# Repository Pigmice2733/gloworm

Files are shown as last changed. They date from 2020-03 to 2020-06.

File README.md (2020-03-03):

# Gloworm

A Raspberry Pi vision tracking module for FRC.

* Powered directly off the PDP (built-in Raspberry Pi PSU)
* Cheap, utilizing off the shelf parts and a 3D printed case (~$120 including RPi 4, camera, PCB, fasteners)
* Fully dimmable ~500 lumen output (6x Cree XP-E2 Green LEDs)
* Compact design (100mm x 74mm x 25mm)

<br />This work is licensed under a <a rel="license" href="http://creativecommons.org/licenses/by-nc-sa/4.0/">Creative Commons Attribution-NonCommercial-ShareAlike 4.0 International License</a>.

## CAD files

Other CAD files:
case/Assembled Gloworm.SLDASM
case/Raspberry Pi 4.SLDPRT
case/M2.5 11mm Spacer.SLDPRT
case/Gloworm PCB.SLDPRT
case/Bottom Case.SLDPRT
case/Top Case.SLDPRT
case/Camera Module.SLDPRT

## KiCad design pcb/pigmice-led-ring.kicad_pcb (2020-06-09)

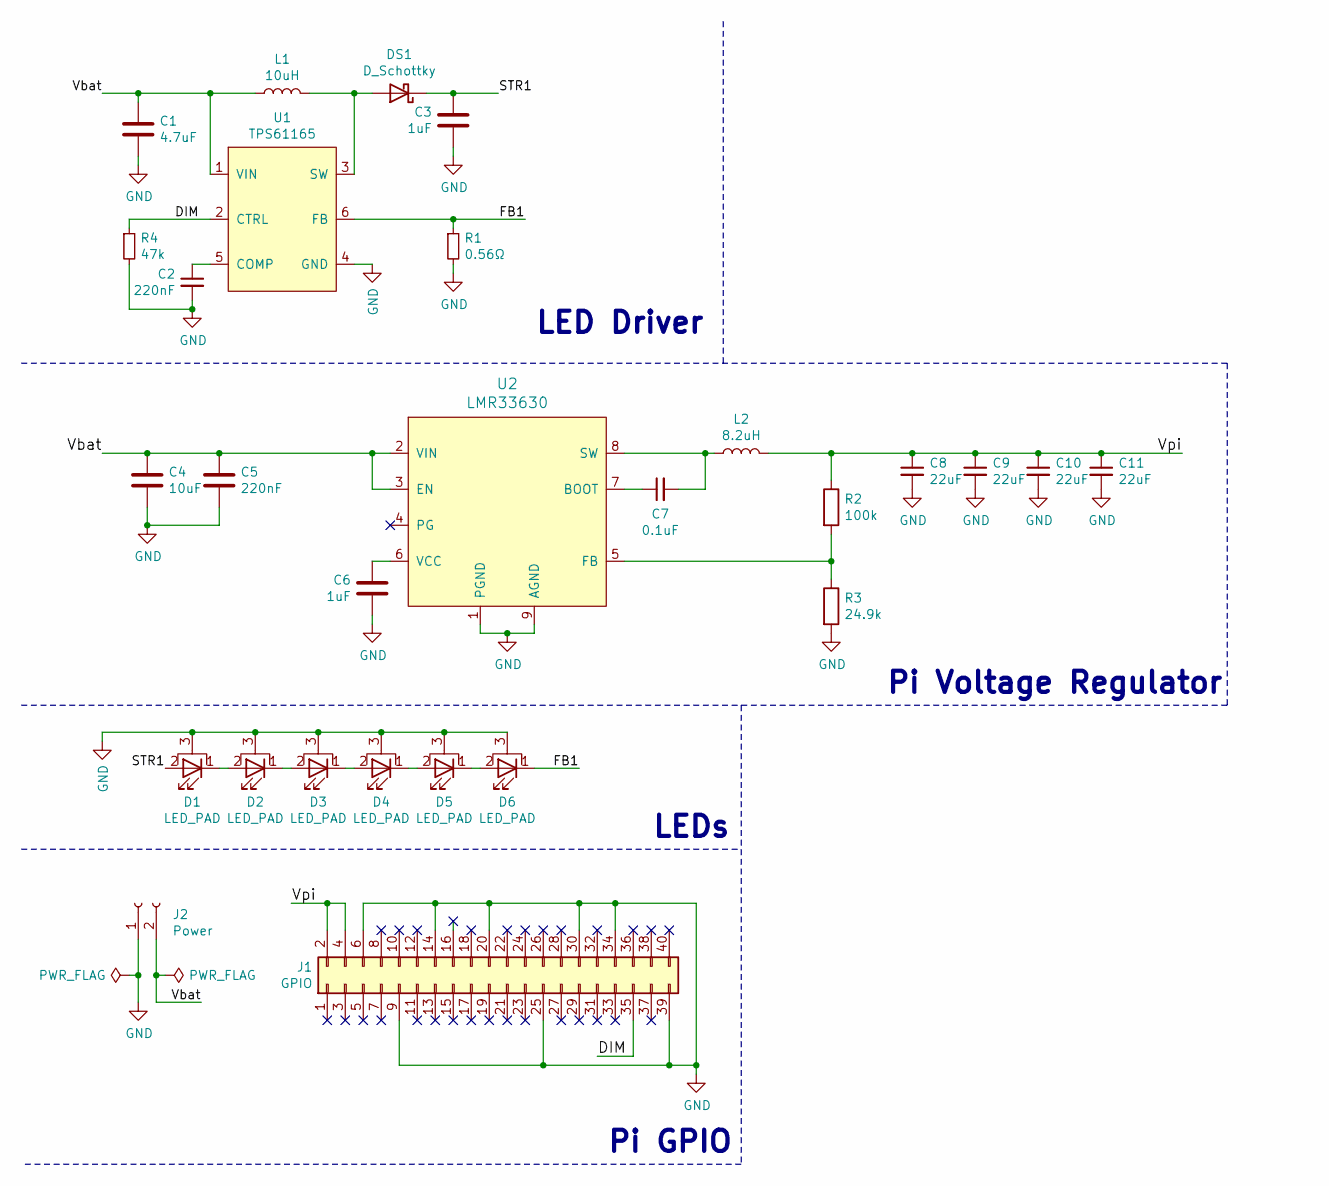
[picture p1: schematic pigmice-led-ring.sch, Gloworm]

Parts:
C1: 4.7uF; C_0805_2012Metric; Digikey 445-172480-1-ND
C2: 220nF; C_0805_2012Metric; Digikey 490-13311-1-ND
C3, C6: 1uF; C_0603_1608Metric; Digikey 1276-6524-1-ND
C4: 10uF; C_1210_3225Metric; Digikey 1276-3388-1-ND
C5: 220nF; C_0603_1608Metric; Digikey 490-5402-1-ND
C7: 0.1uF; C_0603_1608Metric; Digikey 490-16327-1-ND
C8, C9, C10, C11: 22uF; C_1210_3225Metric; Digikey 490-14682-1-ND
D1, D2, D3, D4, D5, D6: LED_PAD; LED_Cree-XP; Digikey XPEBGR-L1-0000-00D01CT-ND
DS1: D_Schottky; D_SOD-123; Digikey MBR0540CT-ND
J1: GPIO; PinSocket_2x20_P2.54mm_Vertical; Digikey A26468-ND
J2: Power; TE_282837-2; Digikey A113320-ND
L1: 10uH; IND_#A915AY-100M=P3; Digikey 490-16513-1-ND
L2: 8.2uH; L_Vishay_IHLP-2525; Digikey 541-1012-1-ND
R1: 0.56Ω; R_0805_2012Metric; Digikey P19302CT-ND
R2: 100k; R_0603_1608Metric; Digikey P100KDBCT-ND
R3: 24.9k; R_0603_1608Metric; Digikey P24.9KDBCT-ND
R4: 47k; R_0805_2012Metric; Digikey 311-47KARCT-ND
U1: TPS61165; SOT-23-6; Digikey 296-27597-1-ND
U2: LMR33630; Texas_HSOP-8-1EP_3.9x4.9mm_P1.27mm_ThermalVias; Digikey 296-49763-1-ND

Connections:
/DIM: J1.35, R4.1, U1.2 (CTRL)
/FB1: D6.1 (K), R1.1, U1.6 (FB)
/STR1: C3.1, D1.2 (A), DS1.1 (K)
/Vbat: C1.1, C4.1, C5.1, J2.2, L1.1, U1.1 (VIN), U2.2 (VIN), U2.3 (EN)
/Vpi: C8.1, C9.1, C10.1, C11.1, J1.2, J1.4, L2.2, R2.1
GND: C1.2, C2.2, C3.2, C4.2, C5.2, C6.2, C8.2, C9.2, C10.2, C11.2, D1.3 (PAD), D2.3 (PAD), D3.3 (PAD), D4.3 (PAD), D5.3 (PAD), D6.3 (PAD), J1.6, J1.9, J1.14, J1.20, J1.25, J1.30, J1.34, J1.39, J2.1, R1.2, R3.2, R4.2, U1.4 (GND), U2.1 (PGND), U2.9 (AGND)
unnamed: C2.1, U1.5 (COMP)
unnamed: C6.1, U2.6 (VCC)
unnamed: C7.1, U2.7 (BOOT)
unnamed: C7.2, L2.1, U2.8 (SW)
unnamed: D1.1 (K), D2.2 (A)
unnamed: D2.1 (K), D3.2 (A)
unnamed: D3.1 (K), D4.2 (A)
unnamed: D4.1 (K), D5.2 (A)
unnamed: D5.1 (K), D6.2 (A)
unnamed: DS1.2 (A), L1.2, U1.3 (SW)
unnamed: R2.2, R3.1, U2.5 (FB)

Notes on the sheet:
LED Driver
Pi Voltage Regulator
LEDs
Pi GPIO

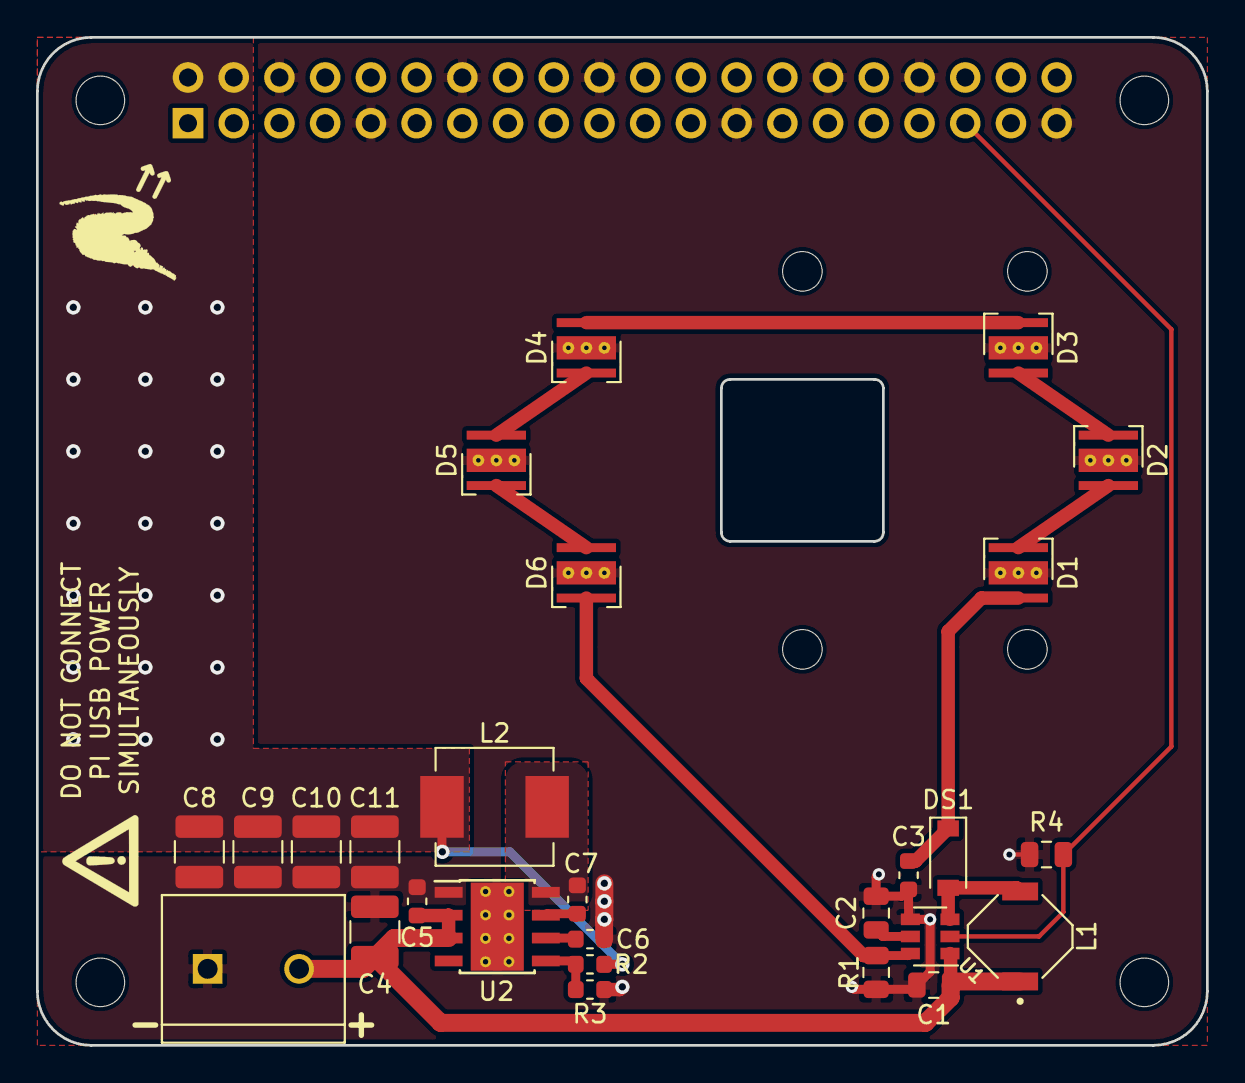
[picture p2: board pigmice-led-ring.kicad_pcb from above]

Board: 2 copper layers, 65.0 x 56.0 mm, 28 parts (1 on the bottom side), 17 nets.

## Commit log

2020-03-03 Add KiCAD PCB files
    [pigmice-led-ring.csv, pigmice-led-ring.kicad_pcb, pigmice-led-ring.sch]
2020-03-03 Add case CAD files
    [Assembled Gloworm.SLDASM, Bottom Case.SLDPRT, Camera Module.SLDPRT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]
2020-03-04 Cleanup PCB
    - Order 5v output capacitors
    - Don't show J1 and J2 footprints
    - Add OSHW logo to the back
    [pigmice-led-ring.kicad_pcb]
2020-06-09 Better .gitignore for PCB
    [pigmice-led-ring.csv]
2020-06-09 Clean up libraries, schematic, PCB
    * Consolidate footprint and symbol libraries
    * Fix Cree XP E-2 thermal vias
    * GND planes on both sides
    * Vpi copper fill on both sides, connected with vias
    * No Vbat copper fill, replaced with 1mm trace
    * Fix all DRC and ERC errors
    [pigmice-led-ring.kicad_pcb, pigmice-led-ring.sch]
2020-06-09 Add DIM pull-down, fixup BOM, zone tolerances
    [pigmice-led-ring.kicad_pcb, pigmice-led-ring.sch]
